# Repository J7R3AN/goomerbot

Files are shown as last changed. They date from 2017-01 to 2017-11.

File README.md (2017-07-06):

# goomerbot
FL Poly MakerSpace Open Source 3D Printer
Work in progress more to come...
 
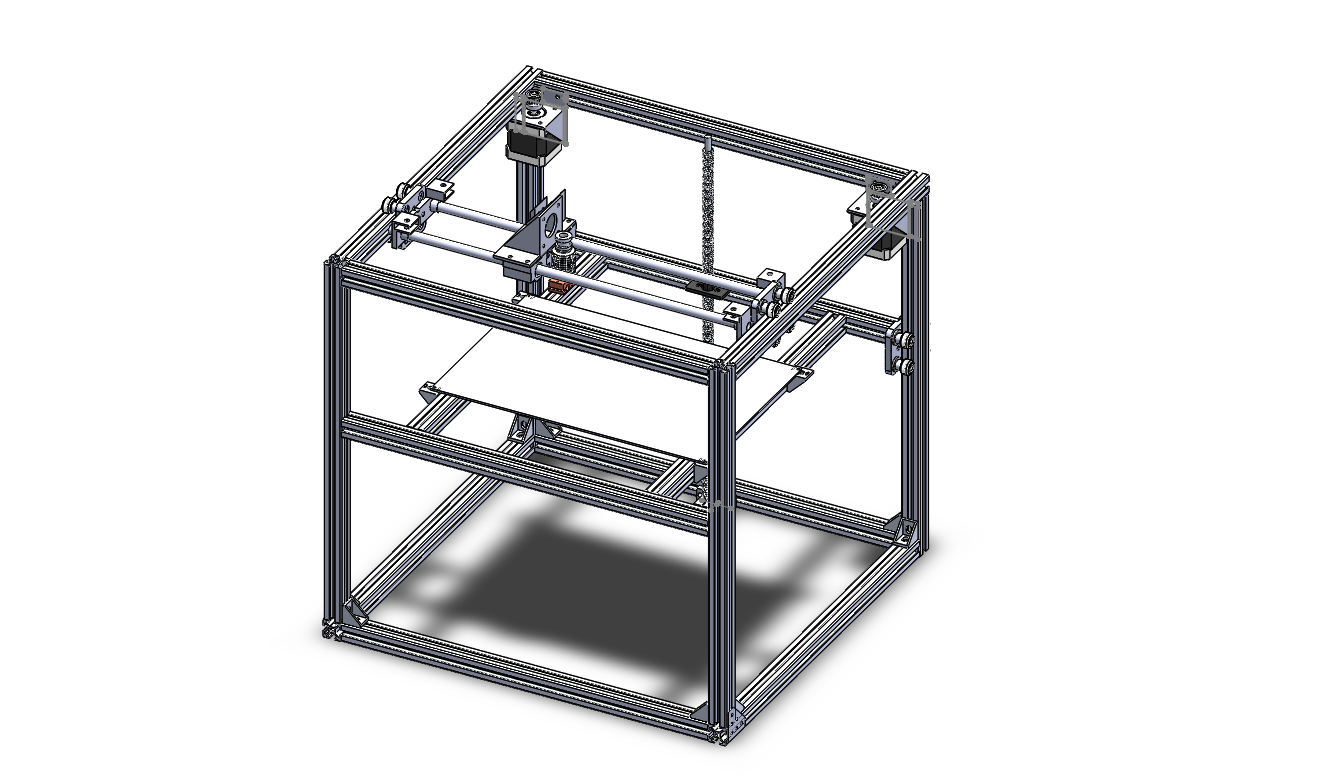
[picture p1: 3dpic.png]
3-D Printer


Update 3-24-2017:
First setup and designs progress
Looks promising... fine-tuning and adjusting peices
Top-Down
Side
Extruder
3D Iterations

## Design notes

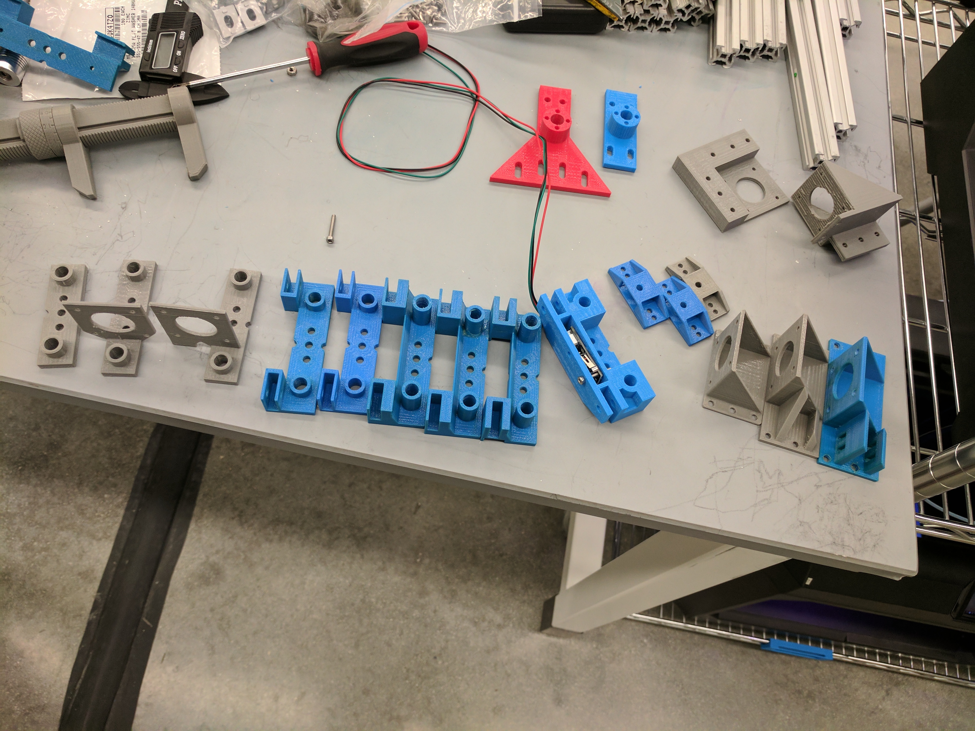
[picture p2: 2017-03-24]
img/Pictures/Redesigns.jpg

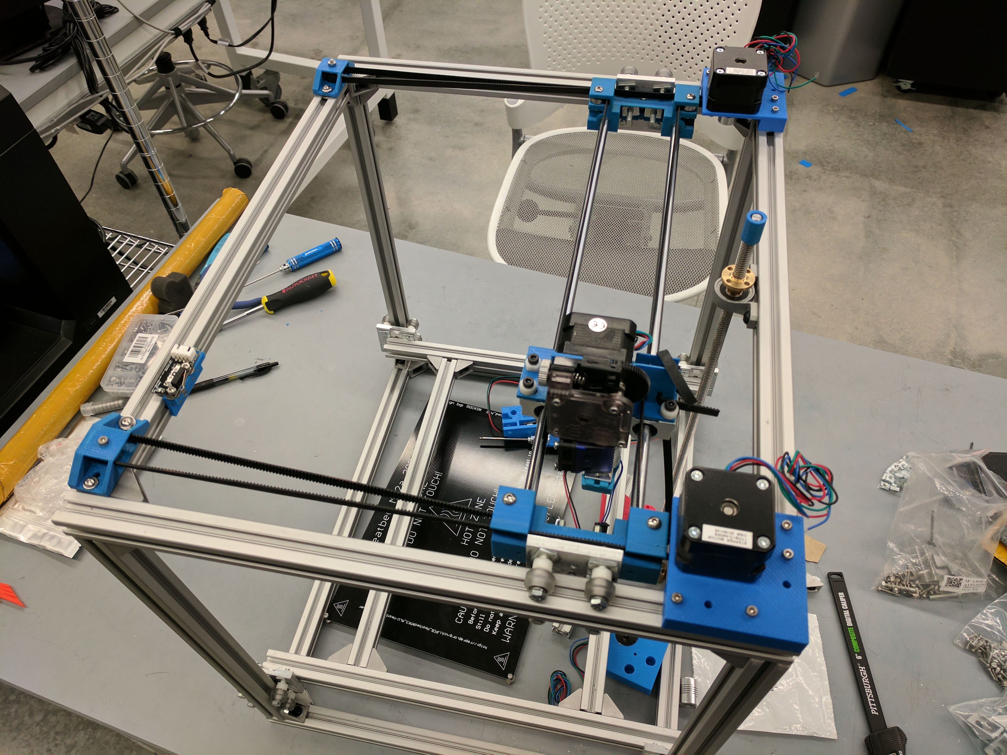
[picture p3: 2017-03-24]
img/Pictures/Top_down.jpg

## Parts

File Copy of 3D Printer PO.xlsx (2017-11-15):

Part | Amount(in) | Quantity | Cost | Link | total
Cast Croner Bracket |  | 28.00 | 10.99/ 10 | Amazon (https://www.amazon.com/dp/B0192F98HO/ref=biss_dp_t_asn) | $38.50 | 2 packs of 25
m5 screw(pack of 100) |  | 1.00 | 6.99 | Amazon (https://www.amazon.com/iExcell-Button-Storage-Machine-Quantity/dp/B073H3GBJM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) | $6.99
bearing housing |  | 1.00 | 12.78/4 | Amazon (https://www.amazon.com/SCS8UU-Linear-Motion-Bearing-Bushing/dp/B00UVA9G9A) | $12.78 | 1 pack of 4
Nema 17 |  | 4.00 | 12.00 | Amazon (https://www.amazon.com/Stepping-Motor-26Ncm-36-8oz-Printer/dp/B00PNEQ9T4) | $48.00
T nuts (pack of 100) |  | 1.00 | 12.99 | Amazon (https://www.amazon.com/TOPINSTOCK-Post-Assembly-Aluminum-Profile/dp/B01FOC6A70) | $12.99 | can be split
M3 Screws (pack of 100) |  | 1.00 | 8.00 | Amazon (https://www.amazon.com/M3-0-50-Button-Socket-Stainless-Quantity/dp/B01F7OKH60) | $8.00 | can be split
Arduino mega w ramps |  | 1.00 | 33.63 | Amazon (https://www.amazon.com/OSOYOO-Printer-Controller-Stepper-Heatsink/dp/B0111ZSS2O) | $33.63
200x300 Heated bed |  | 1.00 | 21.99 | Amazon (https://www.amazon.com/TriGorilla-Aluminum-Heatbed-Hotbed-Printer/dp/B01FCVZ36M) | $21.99
belt, bearings, gear and pulley kit |  | 1.00 | 17.99 | Amazon (https://www.amazon.com/Orish-Printer-Rostock-Movement-Shielded/dp/B01JPD4SBE) | $17.99
PEI sheet 12 by 12 |  | 1.00 | 19.95 | Amazon (https://www.amazon.com/Gizmo-Dorks-Printer-Surface-Polyetherimide/dp/B01KBGJNP0) | $19.95 | can be split for 2
e3D hottend |  | 1.00 | 52.38 | E3D Online (http://e3d-online.com/E3D-v6/Full-Kit/v6-1.75mm-Universal-Bowden) | $52.38
Titan Extruder |  | 1.00 | 54.82 | E3D online (http://e3d-online.com/Titan-Extruder) | $54.82
PET Braided Sleeving |  | 1.00 | 4.64 | Amazon (https://www.amazon.com/gp/product/B00H2R9YWY) | $4.64 | cable management
Lead Screw 8mm |  | 1.00 | 9.99 | Amazon (https://www.amazon.com/CTYRZCH-L300mm-Start-Screw-Printer/dp/B016W5NHY2) | $9.99
Endstops |  | 1.00 | 7.98 | Amazon (https://www.amazon.com/BIQU-Endstop-Mechanical-Switch-Printer/dp/B01FX8SR8A) | $7.98
Power supply |  | 1.00 | 17.98 | Amazon (https://www.amazon.com/NEWSTYLE-Universal-Regulated-Switching-Computer/dp/B00MAC9MO6) | $17.98
8x600mm linear shaft |  | 1.00 | 22.70 | Amazon (https://www.amazon.com/8x600mm-linear-printer-Cylinder-Linear/dp/B017SH81D0) | $22.70 | can be split for 2
Shaft Coupler |  | 1.00 | 7.79 | Amazon (https://www.amazon.com/Atwobic-Aluminum-Flexible-Coupler-Coupling/dp/B01FUKAWT8) | $7.79 | can be split for 2
Mini V Gantry Set |  | 3.00 | 30.75 | openbuilds (http://openbuildspartstore.com/mini-v-gantry-set/) | $92.25
 |  |  |  | Total: | $391.31

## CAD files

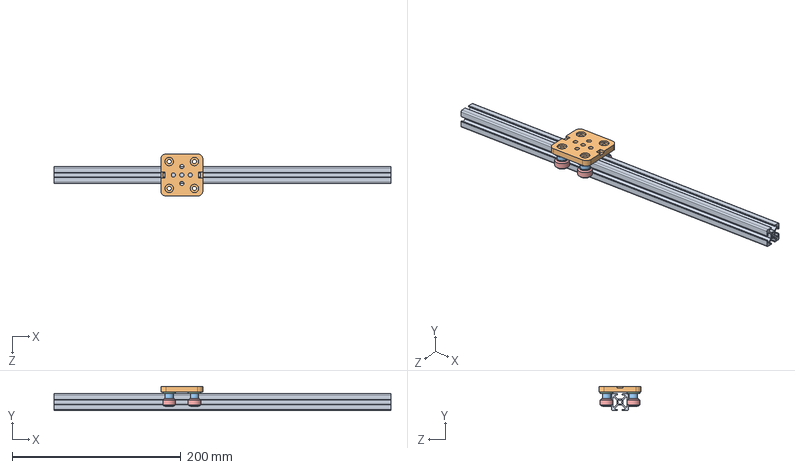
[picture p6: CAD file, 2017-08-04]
SLDMODEL/corexy assembly.SLDASM
400.0 x 28.7 x 50.0 mm
Unviersal Carriage
Aluminum Spacer 6mm x 4
Slot Washer 15 x 5 x 2 x 4
Xtreme Mini V Wheel x 4
Ball Bearing 5 x 10 x 4.2 x 8

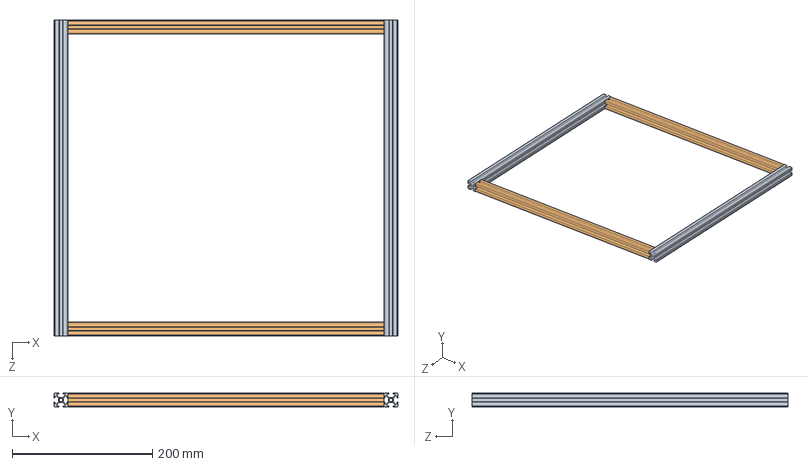
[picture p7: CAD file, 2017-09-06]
Redesign goomerbot/T&B_OB_assembly.SLDASM
490.0 x 20.0 x 450.0 mm
2020_400OB x 2
2020_450OB x 2

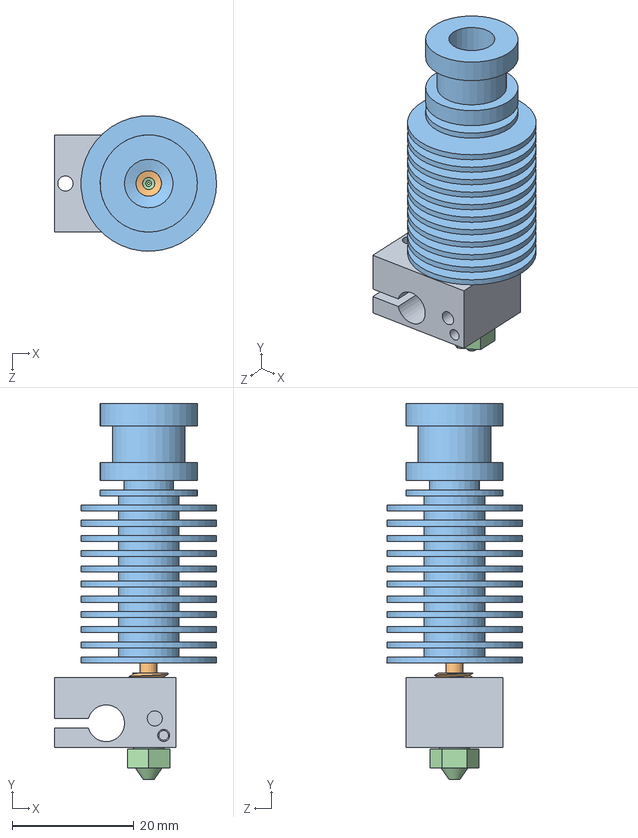
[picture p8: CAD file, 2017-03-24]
SLDMODEL/E3D V6 1.75 Uni model.SLDASM
26.6 x 61.9 x 22.3 mm
V6-BLOCK
V6-175-BREAK
V6-175-SINK
V6-NOZZLE-175-035

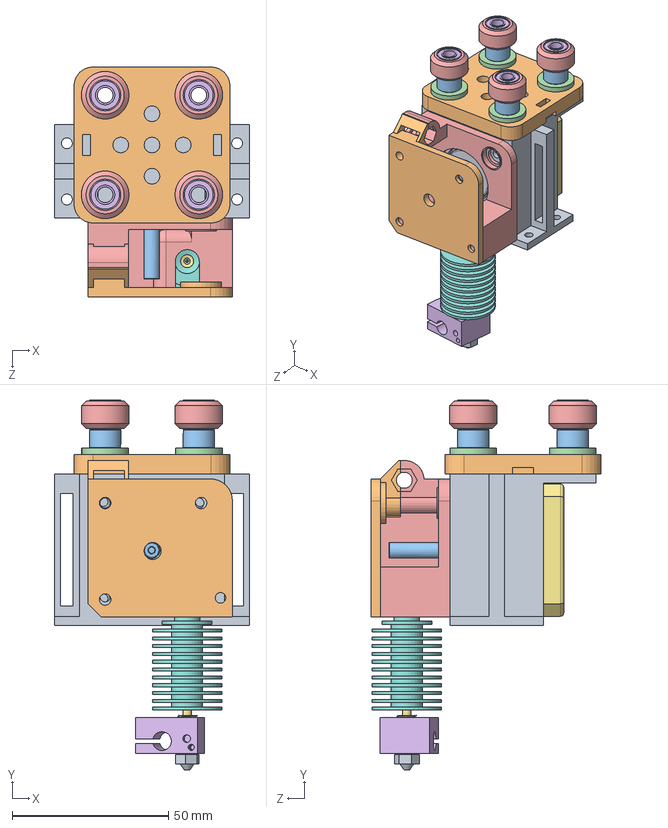
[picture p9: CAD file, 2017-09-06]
Redesign goomerbot/x-y_extruder_assembly.SLDASM
62.5 x 118.5 x 73.7 mm
titan extruder-OB
Unviersal Carriage
Aluminum Spacer 6mm x 4
Slot Washer 15 x 5 x 2 x 4
Xtreme Mini V Wheel x 4
Ball Bearing 5 x 10 x 4.2 x 8
Base
Cuerpo
Tapa
pan cross head_am x 4
Eje
instrument ball bearing_68_am x 2
e3d extruder
V6-BLOCK
V6-175-BREAK
V6-175-SINK
V6-NOZZLE-175-035
e3d extruder_cover

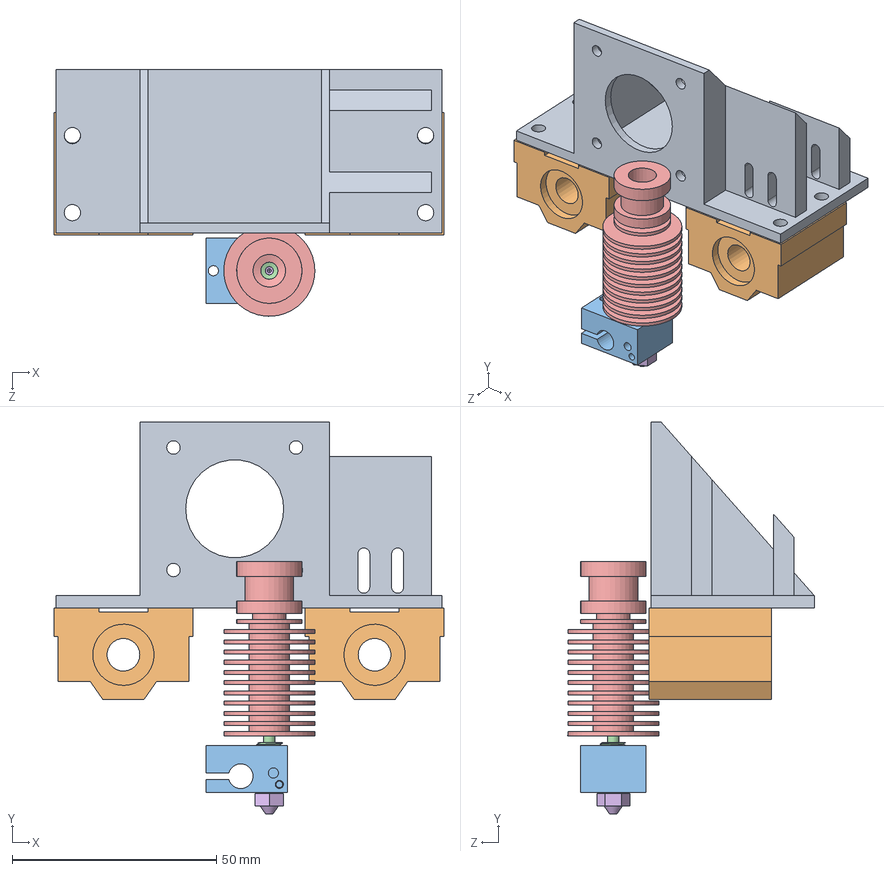
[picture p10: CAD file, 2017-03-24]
SLDMODEL/Extruder carriage.SLDASM
95.5 x 96.0 x 60.4 mm
titan extruder
linear bearings x 2
V6-BLOCK
V6-175-BREAK
V6-175-SINK
V6-NOZZLE-175-035

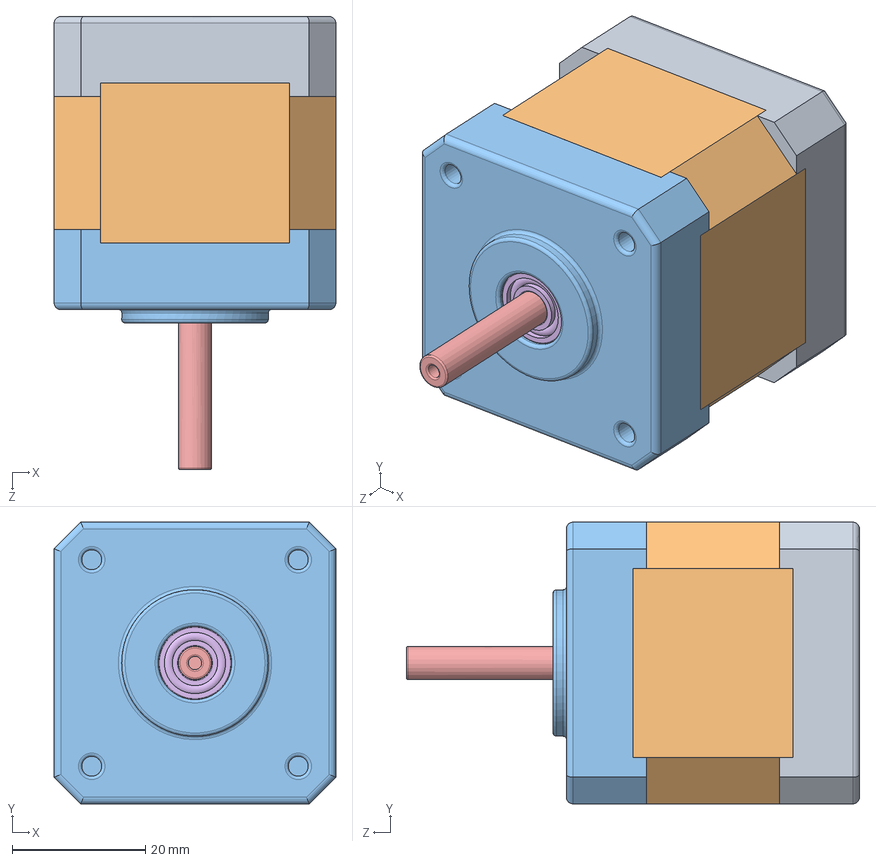
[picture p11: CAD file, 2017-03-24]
SLDMODEL/NEMA 17.SLDASM
42.3 x 42.3 x 68.0 mm
Base
Cuerpo
Tapa
pan cross head_am x 4
Eje
instrument ball bearing_68_am x 2

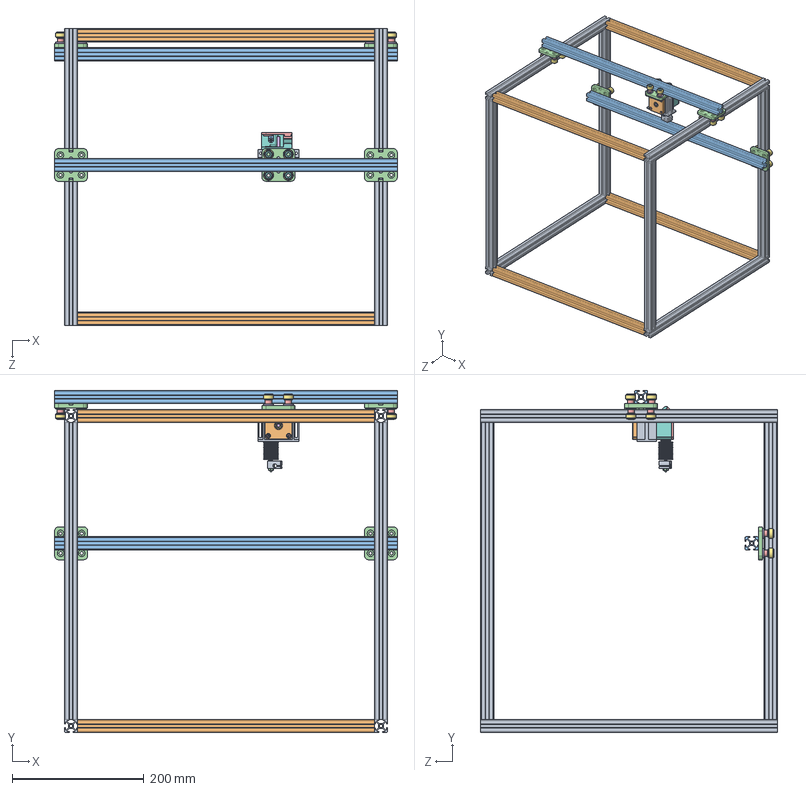
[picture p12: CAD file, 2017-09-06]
Redesign goomerbot/Gommerbot v1.0.SLDASM
520.2 x 518.8 x 450.0 mm
2020_400OB x 8
2020_450OB x 4
2020_520OB x 2
Unviersal Carriage x 5
Aluminum Spacer 6mm x 20
Slot Washer 15 x 5 x 2 x 20
Xtreme Mini V Wheel x 20
Ball Bearing 5 x 10 x 4.2 x 40
titan extruder-OB
Base
Cuerpo
Tapa
pan cross head_am x 4
Eje
instrument ball bearing_68_am x 2
e3d extruder
V6-BLOCK
V6-175-BREAK
V6-175-SINK
V6-NOZZLE-175-035
e3d extruder_cover

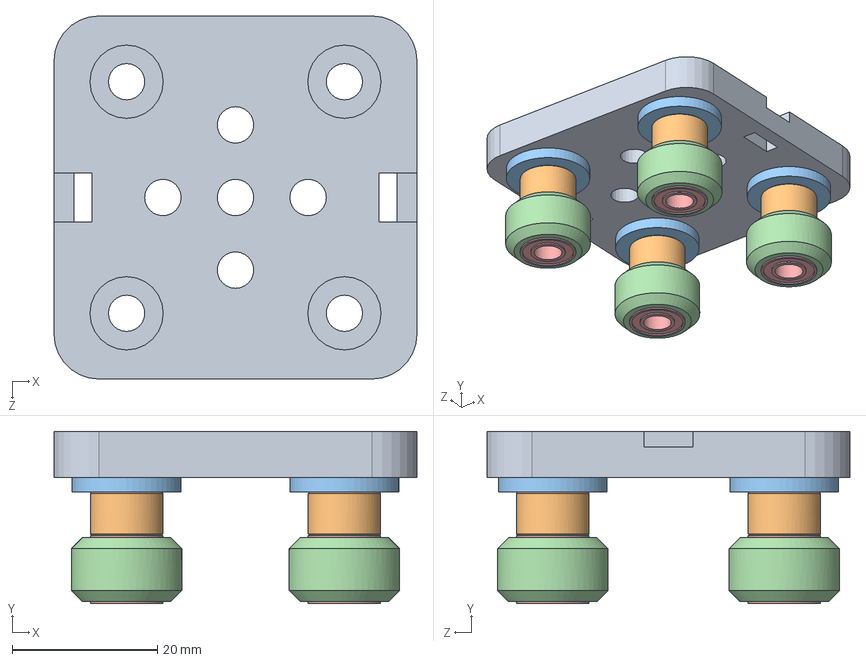
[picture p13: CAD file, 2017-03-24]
SLDMODEL/carriage assembly.SLDASM
50.0 x 23.8 x 50.0 mm
Unviersal Carriage
Aluminum Spacer 6mm x 4
Slot Washer 15 x 5 x 2 x 4
Xtreme Mini V Wheel x 4
Ball Bearing 5 x 10 x 4.2 x 8

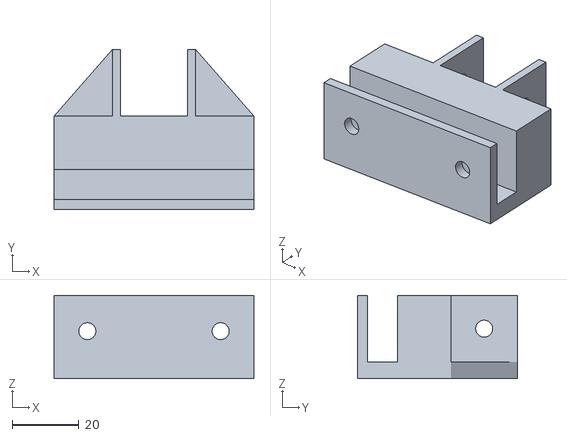
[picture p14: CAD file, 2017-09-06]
Redesign goomerbot/2X_OB H-frame gantryv2.STL
60.0 x 48.0 x 25.0

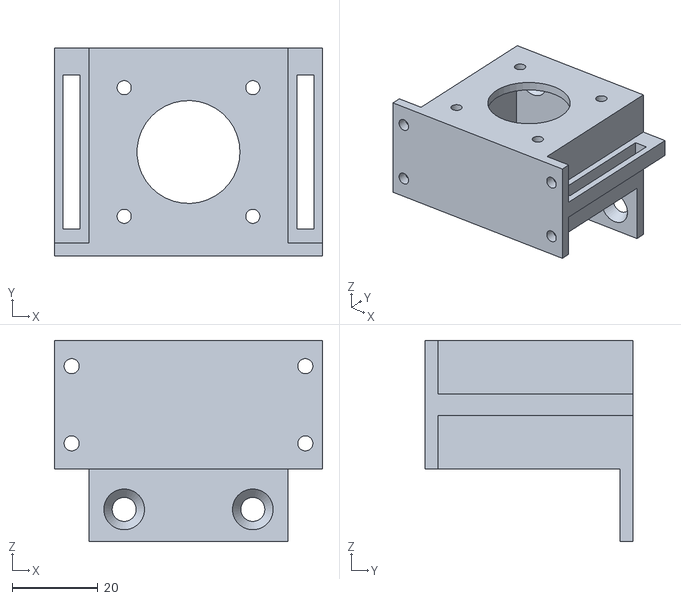
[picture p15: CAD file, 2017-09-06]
Redesign goomerbot/1X_ titan extruder-OB.STL
62.5 x 48.5 x 46.9

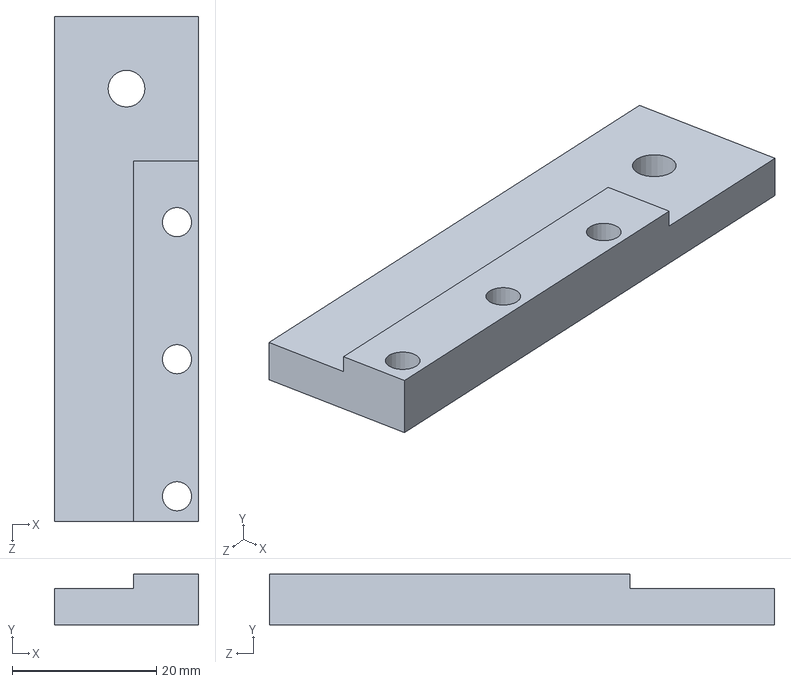
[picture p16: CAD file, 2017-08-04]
SLDMODEL/y-endstop.SLDPRT
20.0 x 7.00 x 70.0 mm

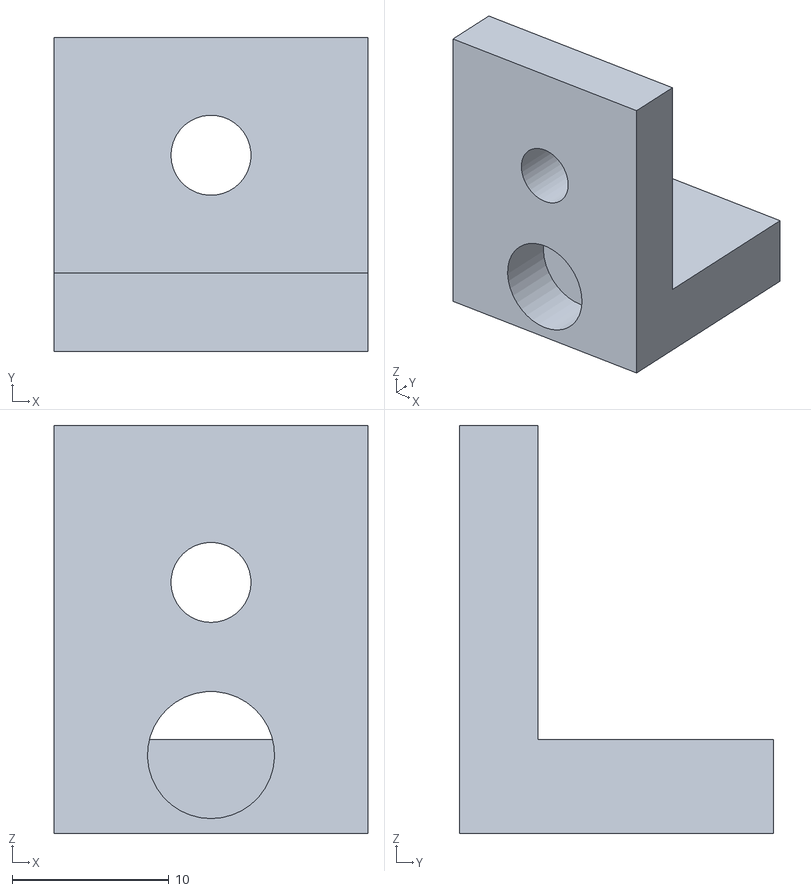
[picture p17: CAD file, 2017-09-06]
Redesign goomerbot/2X smoothrod to OB.STL
20.0 x 20.0 x 26.0

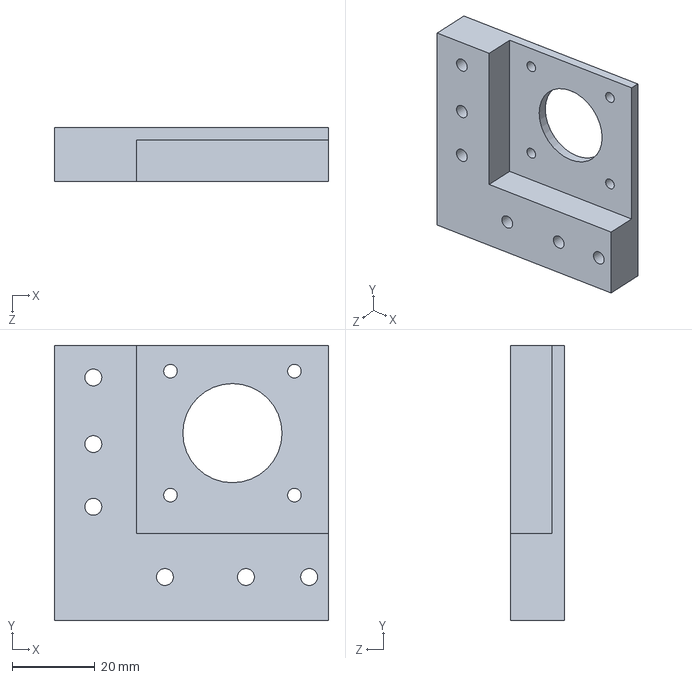
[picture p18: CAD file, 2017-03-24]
SLDMODEL/y motor mount mirrored.SLDPRT
66.3 x 66.6 x 13.0 mm

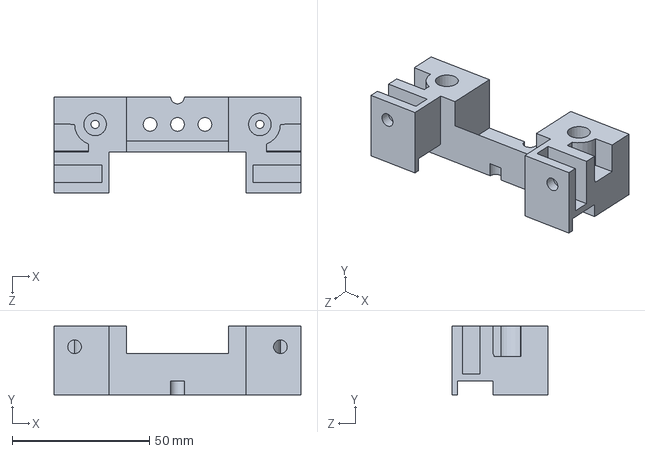
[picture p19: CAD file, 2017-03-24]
SLDMODEL/1-carriage to smooth rod H frame.SLDPRT
90.0 x 25.0 x 35.0 mm

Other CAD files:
SLDMODEL/NEMA 17 with T5 Pulley.SLDASM
SLDMODEL/titan extruder-OB.SLDPRT
Redesign goomerbot/titan extruder-OB.SLDPRT
Redesign goomerbot/2020_520OB.SLDPRT
Redesign goomerbot/200x300 build plate.SLDPRT
Redesign goomerbot/2020_200OB.SLDPRT
Redesign goomerbot/2020_400OB.SLDPRT
Redesign goomerbot/2020_450OB.SLDPRT
Redesign goomerbot/2X_single-bearing OB H-frame.STL
Redesign goomerbot/8mm Acme Nut Plate.SLDPRT
Redesign goomerbot/Cast Corner Bracket.SLDPRT
Redesign goomerbot/OB H-frame gantry.SLDPRT
Redesign goomerbot/arduino-mega-mount.SLDPRT
Redesign goomerbot/arduino-mega-mount.STL
Redesign goomerbot/linear bearings.SLDPRT
Redesign goomerbot/single-bearing OB H-frame.SLDPRT
Redesign goomerbot/smooth rod.SLDPRT
Redesign goomerbot/smoothrod to OB.SLDPRT
Redesign goomerbot/y motor mount.SLDPRT
SLDMODEL/2-belt pulley.SLDPRT
SLDMODEL/330-2020.SLDPRT
SLDMODEL/350-2020.SLDPRT
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

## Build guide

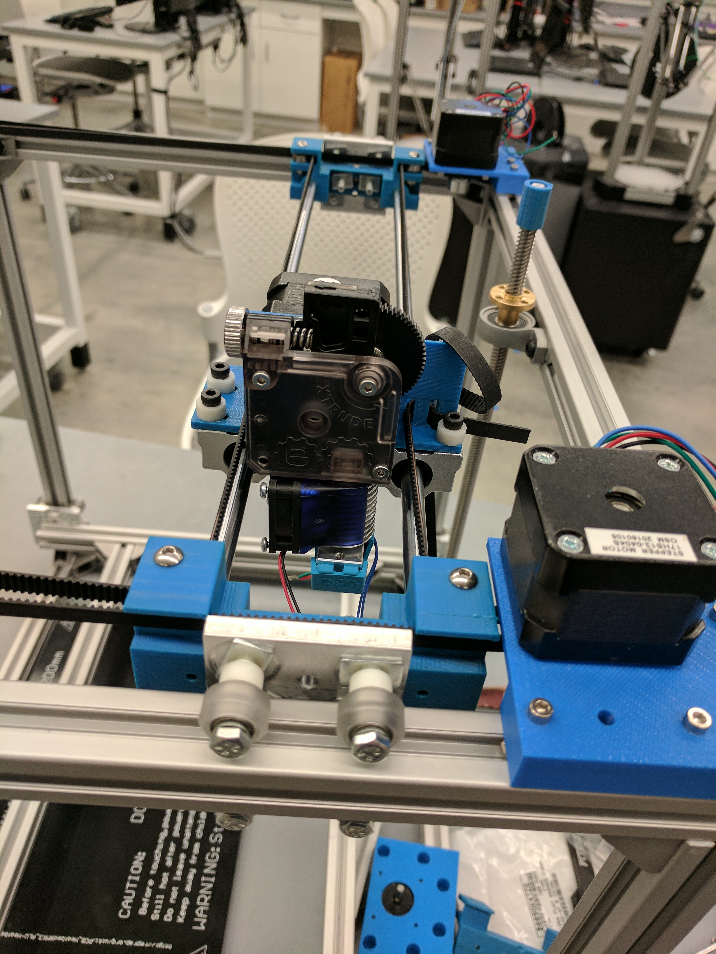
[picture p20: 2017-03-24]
img/Pictures/extruder_assembly.jpg

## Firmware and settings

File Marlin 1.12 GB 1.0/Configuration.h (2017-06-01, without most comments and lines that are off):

#define CONFIGURATION_H
#define CONFIGURATION_H_VERSION 010100
#define STRING_CONFIG_H_AUTHOR "(none, default config)" // Who made the changes.
#define SHOW_BOOTSCREEN
#define STRING_SPLASH_LINE1 SHORT_BUILD_VERSION // will be shown during bootup in line 1
#define STRING_SPLASH_LINE2 WEBSITE_URL         // will be shown during bootup in line 2
#define SERIAL_PORT 0
#define BAUDRATE 250000
  #define MOTHERBOARD BOARD_RAMPS_14_EFB
#define CUSTOM_MACHINE_NAME "GoomerBot"
#define EXTRUDERS 1
#define POWER_SUPPLY 0
#define TEMP_SENSOR_0 5
#define TEMP_SENSOR_1 0
#define TEMP_SENSOR_2 0
#define TEMP_SENSOR_3 0
#define TEMP_SENSOR_4 0
#define TEMP_SENSOR_BED 13
#define DUMMY_THERMISTOR_998_VALUE 25
#define DUMMY_THERMISTOR_999_VALUE 100
#define MAX_REDUNDANT_TEMP_SENSOR_DIFF 10
#define TEMP_RESIDENCY_TIME 10  // (seconds)
#define TEMP_HYSTERESIS 3       // (degC) range of +/- temperatures considered "close" to the target one
#define TEMP_WINDOW     1       // (degC) Window around target to start the residency timer x degC early.
#define TEMP_BED_RESIDENCY_TIME 10  // (seconds)
#define TEMP_BED_HYSTERESIS 3       // (degC) range of +/- temperatures considered "close" to the target one
#define TEMP_BED_WINDOW     1       // (degC) Window around target to start the residency timer x degC early.
#define HEATER_0_MINTEMP 5
#define HEATER_1_MINTEMP 5
#define HEATER_2_MINTEMP 5
#define HEATER_3_MINTEMP 5
#define HEATER_4_MINTEMP 5
#define BED_MINTEMP 5
#define HEATER_0_MAXTEMP 275
#define HEATER_1_MAXTEMP 275
#define HEATER_2_MAXTEMP 275
#define HEATER_3_MAXTEMP 275
#define HEATER_4_MAXTEMP 275
#define BED_MAXTEMP 150
#define PIDTEMP
#define BANG_MAX 255 // limits current to nozzle while in bang-bang mode; 255=full current
#define PID_MAX BANG_MAX // limits current to nozzle while PID is active (see PID_FUNCTIONAL_RANGE below); 255=full current
  #define PID_FUNCTIONAL_RANGE 10 // If the temperature difference between the target temperature and the actual temperature
  #define K1 0.95 //smoothing factor within the PID
  #define  DEFAULT_Kp 22.2
  #define  DEFAULT_Ki 1.08
  #define  DEFAULT_Kd 114
#define PIDTEMPBED
#define MAX_BED_POWER 255 // limits duty cycle to bed; 255=full current
  #define  DEFAULT_bedKp 676.66
  #define  DEFAULT_bedKi 132.38
  #define  DEFAULT_bedKd 864.68
#define PREVENT_COLD_EXTRUSION
#define EXTRUDE_MINTEMP 170
#define PREVENT_LENGTHY_EXTRUDE
#define EXTRUDE_MAXLENGTH 200
#define THERMAL_PROTECTION_HOTENDS // Enable thermal protection for all extruders
#define THERMAL_PROTECTION_BED     // Enable thermal protection for the heated bed
#define COREXY
#define USE_XMIN_PLUG
#define USE_YMIN_PLUG
#define USE_ZMIN_PLUG
  #define ENDSTOPPULLUP_XMIN
  #define ENDSTOPPULLUP_YMIN
  #define ENDSTOPPULLUP_ZMIN
#define X_MIN_ENDSTOP_INVERTING true // set to true to invert the logic of the endstop.
#define Y_MIN_ENDSTOP_INVERTING true // set to true to invert the logic of the endstop.
#define Z_MIN_ENDSTOP_INVERTING true // set to true to invert the logic of the endstop.
#define X_MAX_ENDSTOP_INVERTING true // set to true to invert the logic of the endstop.
#define Y_MAX_ENDSTOP_INVERTING true // set to true to invert the logic of the endstop.
#define Z_MAX_ENDSTOP_INVERTING true // set to true to invert the logic of the endstop.
#define Z_MIN_PROBE_ENDSTOP_INVERTING true // set to true to invert the logic of the probe.
#define ENDSTOP_INTERRUPTS_FEATURE
#define DEFAULT_AXIS_STEPS_PER_UNIT   { 80, 80, 400, 100 }
#define DEFAULT_MAX_FEEDRATE          { 300, 300, 5, 25 }
#define DEFAULT_MAX_ACCELERATION      { 3000, 3000, 100, 10000 }
#define DEFAULT_ACCELERATION          1500    // X, Y, Z and E acceleration for printing moves
#define DEFAULT_RETRACT_ACCELERATION  10000    // E acceleration for retracts
#define DEFAULT_TRAVEL_ACCELERATION   2000    // X, Y, Z acceleration for travel (non printing) moves
#define DEFAULT_XJERK                 10.0
#define DEFAULT_YJERK                 10.0
#define DEFAULT_ZJERK                  0.4
#define DEFAULT_EJERK                  5.0
#define Z_MIN_PROBE_USES_Z_MIN_ENDSTOP_PIN
#define FIX_MOUNTED_PROBE
#define X_PROBE_OFFSET_FROM_EXTRUDER 28  // X offset: -left  +right  [of the nozzle]
#define Y_PROBE_OFFSET_FROM_EXTRUDER 12  // Y offset: -front +behind [the nozzle]
#define Z_PROBE_OFFSET_FROM_EXTRUDER 0   // Z offset: -below +above  [the nozzle]
#define XY_PROBE_SPEED 8000
#define Z_PROBE_SPEED_FAST HOMING_FEEDRATE_Z
#define Z_PROBE_SPEED_SLOW (Z_PROBE_SPEED_FAST / 2)
#define PROBE_DOUBLE_TOUCH
#define Z_CLEARANCE_DEPLOY_PROBE   10 // Z Clearance for Deploy/Stow
#define Z_CLEARANCE_BETWEEN_PROBES  5 // Z Clearance between probe points
#define Z_PROBE_OFFSET_RANGE_MIN -20
#define Z_PROBE_OFFSET_RANGE_MAX 20
#define X_ENABLE_ON 0
#define Y_ENABLE_ON 0
#define Z_ENABLE_ON 0
#define E_ENABLE_ON 0 // For all extruders
#define DISABLE_X false
#define DISABLE_Y false
#define DISABLE_Z false
#define DISABLE_E false // For all extruders
#define DISABLE_INACTIVE_EXTRUDER true // Keep only the active extruder enabled.
#define INVERT_X_DIR true
#define INVERT_Y_DIR true
#define INVERT_Z_DIR false
#define INVERT_E0_DIR false
#define INVERT_E1_DIR false
#define INVERT_E2_DIR false
#define INVERT_E3_DIR false
#define INVERT_E4_DIR false
#define X_HOME_DIR -1
#define Y_HOME_DIR -1
#define Z_HOME_DIR -1
#define X_MIN_POS 0
#define Y_MIN_POS 0
#define Z_MIN_POS 0
#define X_MAX_POS 200
#define Y_MAX_POS 200
#define Z_MAX_POS 155
#define MIN_SOFTWARE_ENDSTOPS
#define MAX_SOFTWARE_ENDSTOPS
#define HOMING_FEEDRATE_XY (50*60)
#define HOMING_FEEDRATE_Z  (4*60)
#define EEPROM_SETTINGS
  #define EEPROM_CHITCHAT // Please keep turned on if you can.
#define HOST_KEEPALIVE_FEATURE        // Disable this if your host doesn't like keepalive messages
#define DEFAULT_KEEPALIVE_INTERVAL 2  // Number of seconds between "busy" messages. Set with M113.
#define PREHEAT_1_TEMP_HOTEND 180
#define PREHEAT_1_TEMP_BED     70
#define PREHEAT_1_FAN_SPEED     0 // Value from 0 to 255
#define PREHEAT_2_TEMP_HOTEND 235
#define PREHEAT_2_TEMP_BED    65
#define PREHEAT_2_FAN_SPEED     0 // Value from 0 to 255
#define PRINTJOB_TIMER_AUTOSTART
#define LCD_LANGUAGE en
#define DISPLAY_CHARSET_HD44780 JAPANESE
#define SDSUPPORT
#define REPRAP_DISCOUNT_FULL_GRAPHIC_SMART_CONTROLLER
#define SOFT_PWM_SCALE 0
#define SERVO_DELAY 300
#define DEFAULT_NOMINAL_FILAMENT_DIA 3.00   // (mm) Diameter of the filament generally used (3.0 or 1.75mm), also used in the slicer. Used to validate sensor reading.

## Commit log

2016-10-28 Initial Design commit
    Preliminary design for sizing and Parts
    [200x300 build plate.SLDPRT, 330-2020.SLDPRT, 350-2020.SLDPRT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]
2017-01-27 Fixes and Modifications
    [200x300 build plate.SLDPRT, 330-2020.SLDPRT, 350-2020.SLDPRT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]
2017-01-27 Old File
    [aluminium_mount_new.SLDPRT]
2017-03-24 Updates as of 3-24
    NEW setup 3D parts integration
    [1-carriage to smooth rod H frame.SLDPRT, 2-belt pulley.SLDPRT, Cuerpo.SLDPRT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]
2017-06-01 Marlin Software Initial commit
    Made few changes to the Marlin v1.12 software, got the printer to jog and home properly.
2017-08-04 new files 8-3-2017
    [OB H-frame gantry.SLDPRT, single-bearing OB H-frame.SLDPRT, titan extruder-OB.SLDPRT]
2017-08-04 new files 8-3-2017, assembly yet to be added
    [corexy assembly.SLDASM, smoothrod to OB.SLDPRT, y-endstop.SLDPRT]
2017-08-23 redesign
    updated file list, need to add merger and push old files to deprecated list
    [1X_ titan extruder-OB.STL, 200x300 build plate.SLDPRT, 2020_200OB.SLDPRT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]

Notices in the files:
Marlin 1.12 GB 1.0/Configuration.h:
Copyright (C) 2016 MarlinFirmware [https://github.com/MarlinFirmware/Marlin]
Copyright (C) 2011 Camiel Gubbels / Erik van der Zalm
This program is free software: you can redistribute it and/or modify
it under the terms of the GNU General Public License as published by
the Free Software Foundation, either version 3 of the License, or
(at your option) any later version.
